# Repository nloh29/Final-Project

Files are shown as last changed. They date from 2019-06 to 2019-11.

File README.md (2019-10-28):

# Final-Project

## Overview:
  Currently, the most common mode of travel around campus is by walking long distances in a short amount of time. This can be a very time consuming and energy consuming process that would greatly benefit from a more efficient mode of transportation. The goal of this project is to create an electric skateboard that allows students to move around campus in a more timely manner that is cheaper, lasts longer, goes faster, and is safer than the current equivalent. This will require firmware to control the board wirelessly using two microcontrollers, the use of motors and motor driver circuits to physically drive the board, charging via USB-C for easier charging access without the need for a specifically dedicated charging solution, and power distribution/regulation for all of the components involved using a safer battery type.

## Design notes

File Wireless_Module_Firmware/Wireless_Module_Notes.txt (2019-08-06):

Wireless Module Notes:

Here is a cypress document that shows what to include into the .gitignore file.
 and what to include to properly push to the repo.

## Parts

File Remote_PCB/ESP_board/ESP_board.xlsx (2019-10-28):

# | Qty: | Designator | Part #: | Manu. | Description | Distributor | Link
1 | 2 | R1,R2 | ESR03EZPJ472 | Rohm Semi. | 4.7 kOhms ±5% 0.25W, 1/4W Chip Resistor 0603 | Digikey | https://www.digikey.com/product-detail/en/rohm-semiconductor/ESR03EZPJ472/RHM4.7KDCT-ND/1762936
2 | 4 | J1,J2,J3,J4 | 68000-210HLF | Amphenol ICC | CONN HEADER VERT 10POS 2.54MM | Digikey | https://www.digikey.com/product-detail/en/68000-210HLF/609-3258-ND/1878529/?itemSeq=307847159
3 | 1 | D1 | Have
4 | 1 | D2 | Have
5 | 1 | J6 | A113320 | Phoenix | TERM BLK 2P SIDE ENT 5.08MM PCB | Digikey | https://www.digikey.com/product-detail/en/282837-2/A113320-ND/2187973

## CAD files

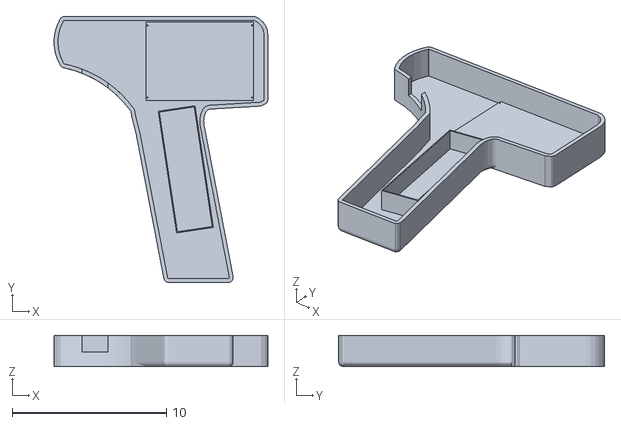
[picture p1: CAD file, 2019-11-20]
Remote_Model/remote_assemblyv2_toPrint.stl
13.9 x 17.2 x 2.03

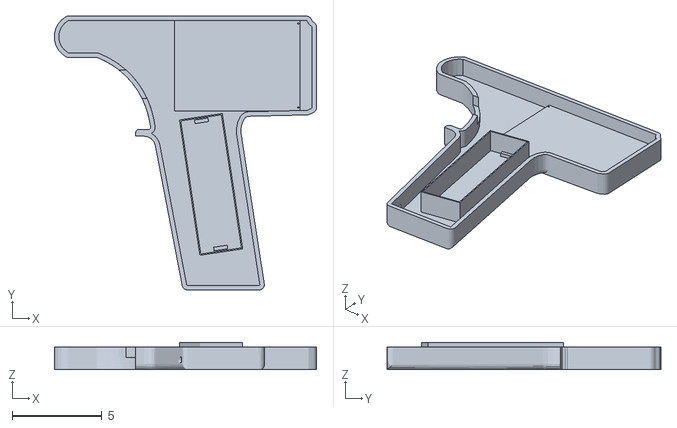
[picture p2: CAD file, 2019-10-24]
Remote_Model/remote_assemblyv2.stl
14.6 x 15.3 x 1.52

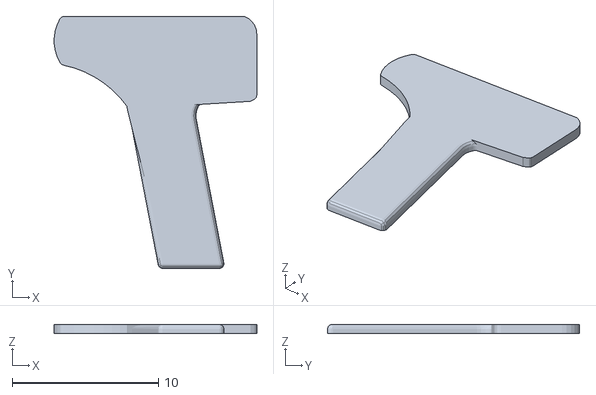
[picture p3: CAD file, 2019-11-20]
Remote_Model/mirror_remote_toPrint.stl
13.9 x 17.2 x 0.635

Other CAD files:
Remote_Model/batteryHousing.ipt
Remote_Model/espHolder.ipt
Remote_Model/remote_assemblyv2.iam
Remote_Model/remote_housing.ipt
Remote_Model/remote_housing_top.ipt
Remote_Model/remote_housing_v2.ipt
Remote_Model/remote_mirrorv2.iam

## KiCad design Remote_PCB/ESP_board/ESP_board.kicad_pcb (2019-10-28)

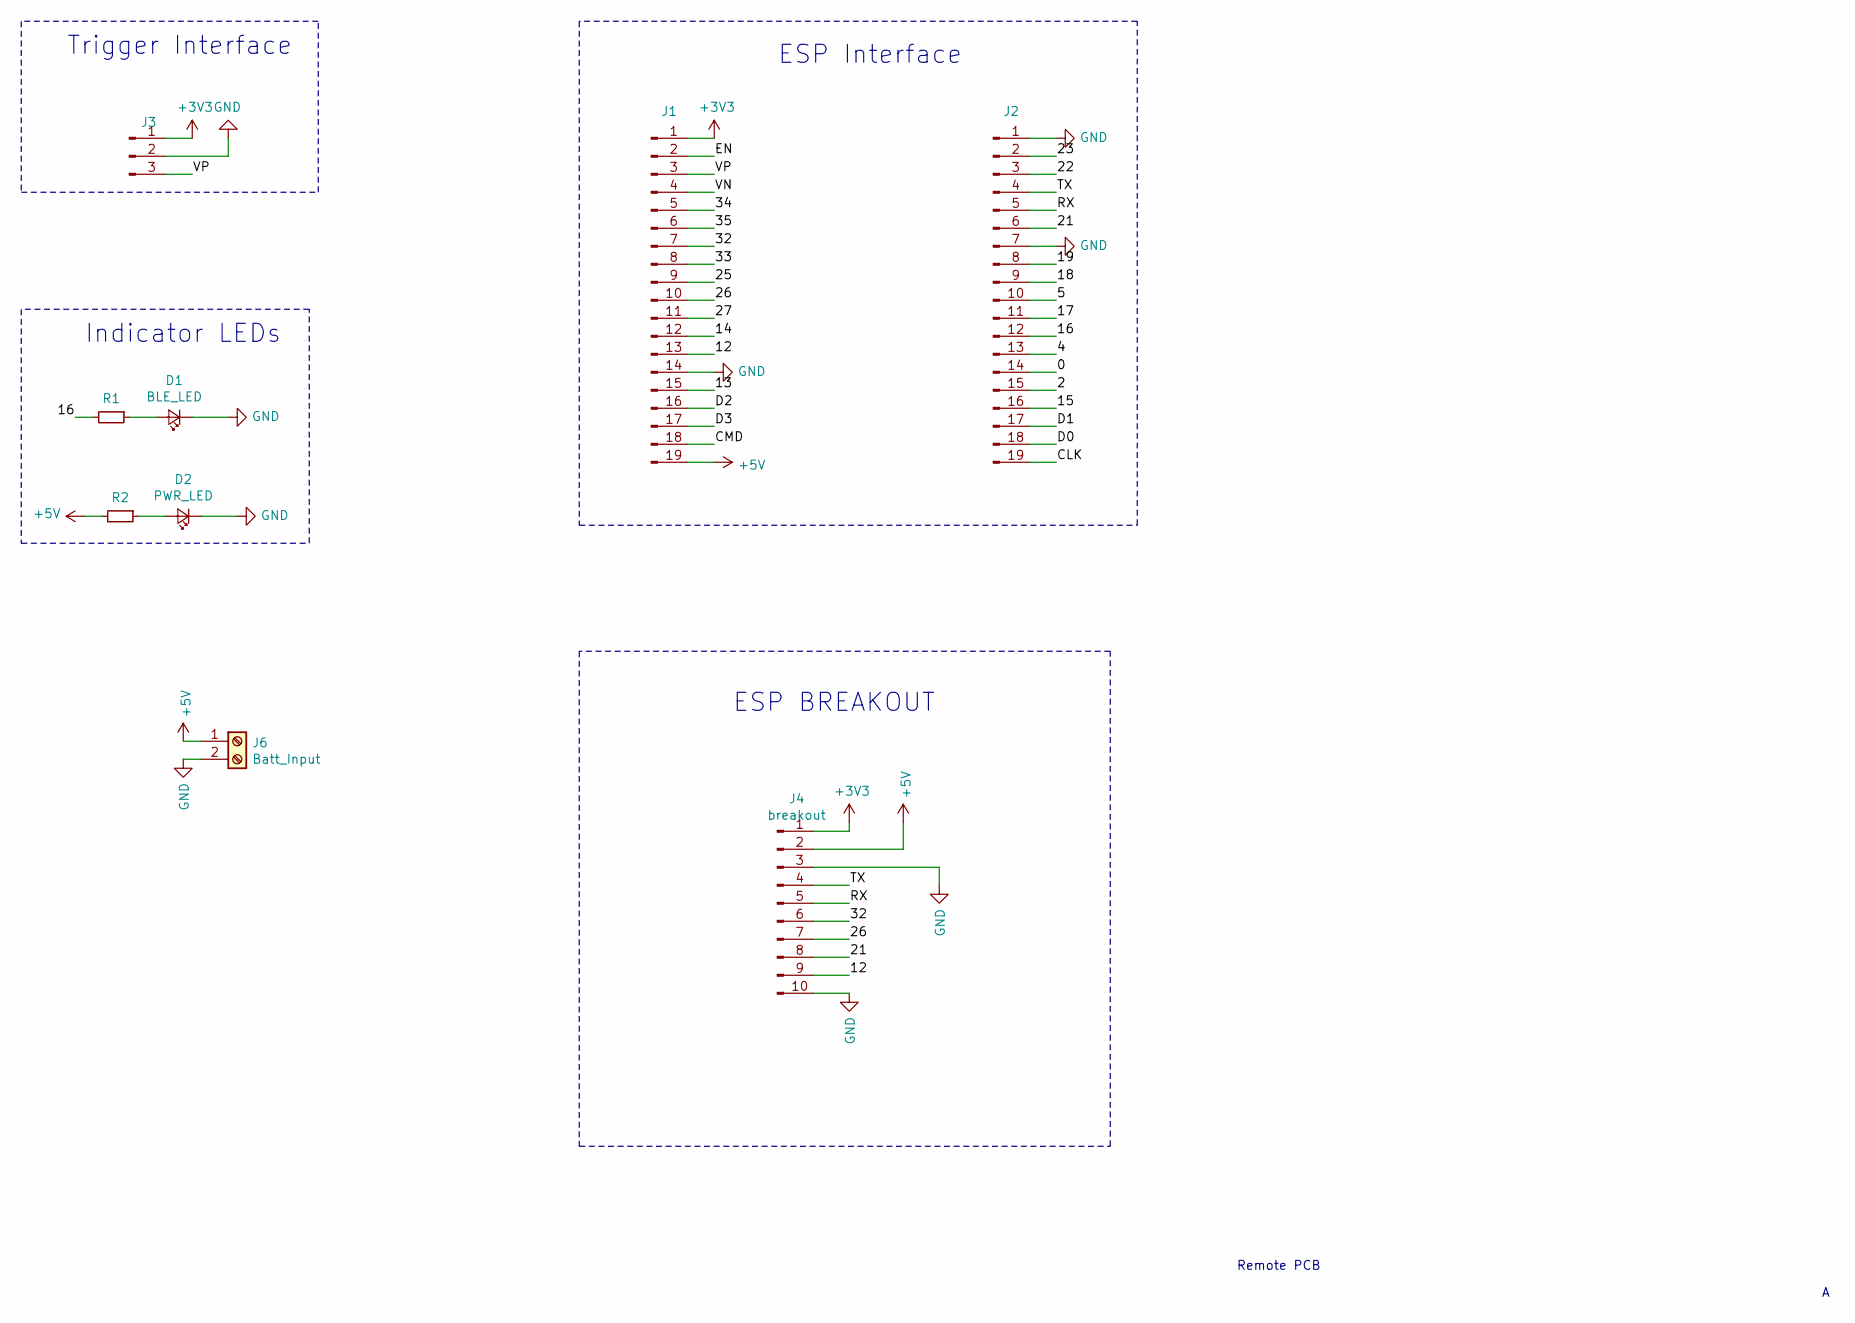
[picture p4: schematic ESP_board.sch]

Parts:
D1: BLE_LED; LED_D2.0mm_W4.0mm_H2.8mm_FlatTop
D2: PWR_LED; LED_D2.0mm_W4.0mm_H2.8mm_FlatTop
J1: leftside; Pin_Header_Straight_1x19_Pitch2.54mm
J2: rightside; Pin_Header_Straight_1x19_Pitch2.54mm
J3: Conn_01x03_Male; Pin_Header_Straight_1x03_Pitch2.54mm
J4: breakout; Pin_Header_Straight_1x10_Pitch2.54mm
J6: Batt_Input; TerminalBlock_bornier-2_P5.08mm
R1, R2: R_Small; R_0603_HandSoldering

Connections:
+3V3: J1.1, J3.1, J4.1
+5V: J1.19, J4.2, J6.1, R2.2
/0: J2.14
/2: J2.15
/4: J2.13
/5: J2.10
/12: J1.13, J4.9
/13: J1.15
/14: J1.12
/15: J2.16
/16: J2.12, R1.2
/17: J2.11
/18: J2.9
/19: J2.8
/21: J2.6, J4.8
/22: J2.3
/23: J2.2
/25: J1.9
/26: J1.10, J4.7
/27: J1.11
/32: J1.7, J4.6
/33: J1.8
/34: J1.5
/35: J1.6
/CLK: J2.19
/CMD: J1.18
/D0: J2.18
/D1: J2.17
/D2: J1.16
/D3: J1.17
/EN: J1.2
/RX: J2.5, J4.5
/TX: J2.4, J4.4
/VN: J1.4
/VP: J1.3, J3.3
GND: D1.1 (K), D2.1 (K), J1.14, J2.1, J2.7, J3.2, J4.3, J4.10, J6.2
unnamed: D1.2 (A), R1.1
unnamed: D2.2 (A), R2.1

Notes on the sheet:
Remote PCB
ESP Interface
Trigger Interface
Indicator LEDs
ESP BREAKOUT

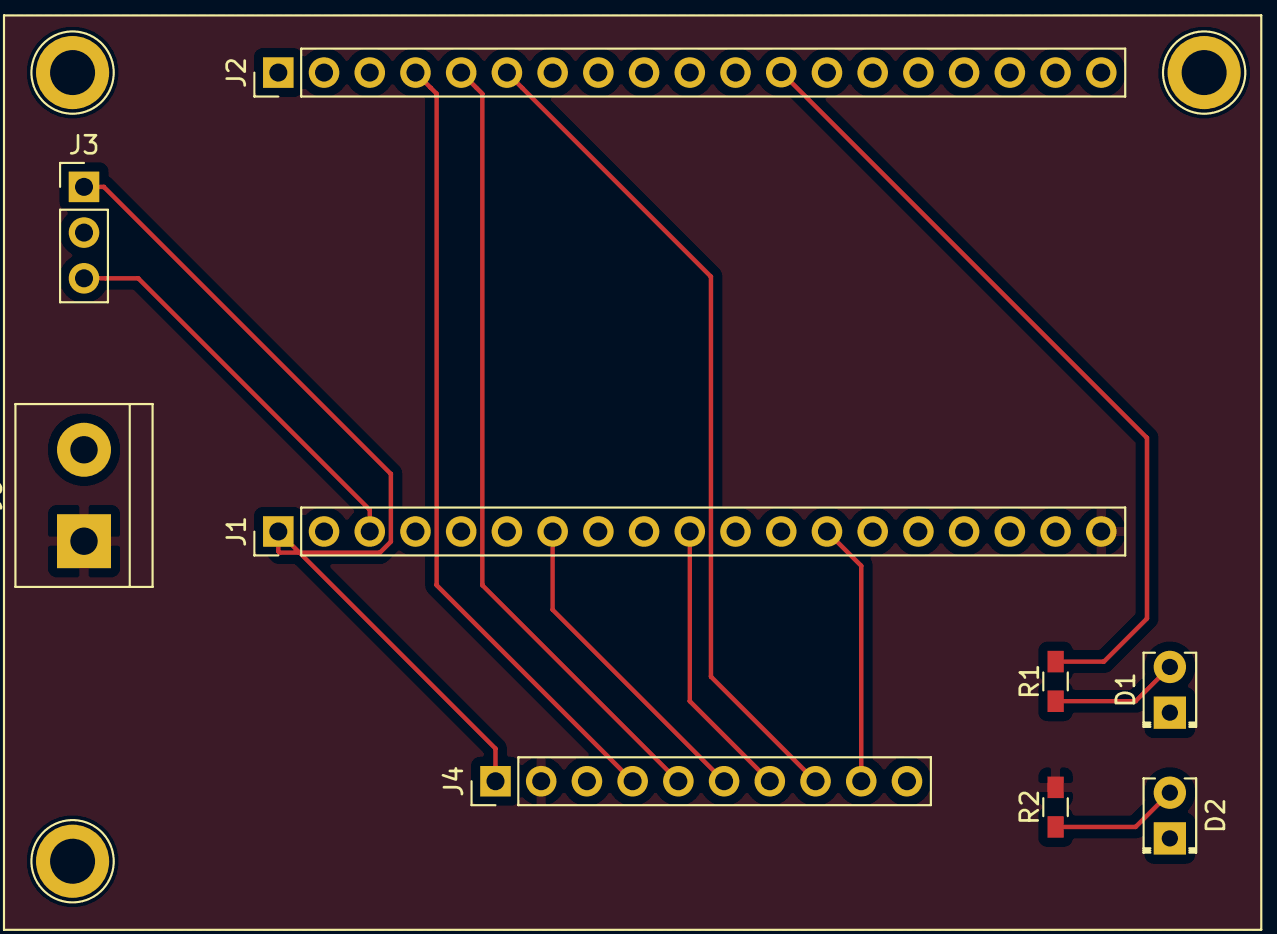
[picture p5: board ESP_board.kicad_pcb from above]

Board: 2 copper layers, 9 parts (0 on the bottom side), 13 nets.

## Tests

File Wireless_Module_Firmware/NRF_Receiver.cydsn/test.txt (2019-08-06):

This folder is for the wireless module firmware

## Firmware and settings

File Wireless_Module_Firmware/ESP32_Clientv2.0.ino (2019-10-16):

#include <cstdlib>
#include <string>
#include <sstream>
#include "BLEDevice.h"
#include "Servo.h"

// The remote service we wish to connect to.
static BLEUUID serviceUUID("4fafc201-1fb5-459e-8fcc-c5c9c331914b");
// The characteristic of the remote service we are interested in.
static BLEUUID    charUUID("beb5483e-36e1-4688-b7f5-ea07361b26a8");

static boolean doConnect = false;
static boolean connected = false;
static int discTimer = 0;
static BLERemoteCharacteristic* pRemoteCharacteristic;
static BLEAddress *pServerAddress;
static BLEClient*  pClient;

Servo esc;
std::string prev_val;
int num_retr = 0;
const int pwmPin = 16;
int pwmVal;
int pwmDuty;
char buff[5];

static void notifyCallback(
  BLERemoteCharacteristic* pBLERemoteCharacteristic,
  uint8_t* pData,
  size_t length,
  bool isNotify) {
   // if(pRemoteCharacteristic->canRead()) {
      discTimer = 0;
      
      //Serial.println((char*)pData);
      std::string value = (char*)pData;
      
      //std::string value = pRemoteCharacteristic->readValue();
      std::stringstream ss(value);
      ss >> pwmVal;
      
      //the server has disconnected and now displays nothing, reconnect
//      if(value == "\0"){
//        Serial.println("Disconnected...");
//        doConnect = true;
//        connected = false;
//        esc.writeMicroseconds(1000);
//      }
      
      //server is connected and getting values
      Serial.print("Val: ");
      Serial.println(pwmVal);
      esc.writeMicroseconds(pwmVal);
    //}
}


class MyClientCallback : public BLEClientCallbacks {
  void onConnect(BLEClient* pclient) {
    connected = true;
    doConnect = false;
  }

  void onDisconnect(BLEClient* pclient) {
    Serial.println("Disconnected...");
    doConnect = true;
    connected = false;
    esc.writeMicroseconds(1000);
  }
};


bool connectToServer(BLEAddress pAddress)
{
	Serial.print("Forming a connection to ");
	Serial.println(pAddress.toString().c_str());

	pClient = BLEDevice::createClient();
	Serial.println(" - Created client");

  pClient->setClientCallbacks(new MyClientCallback());
  
	// Connect to the remove BLE Server.
	pClient->connect(pAddress);
	Serial.println(" - Connected to server");

	// Obtain a reference to the service we are after in the remote BLE server.
	BLERemoteService* pRemoteService = pClient->getService(serviceUUID);
	if (pRemoteService == nullptr) {
		Serial.print("Failed to find our service UUID: ");
		Serial.println(serviceUUID.toString().c_str());
		return false;
	}
	Serial.println(" - Found our service");

	// Obtain a reference to the characteristic in the service of the remote BLE server.
	pRemoteCharacteristic = pRemoteService->getCharacteristic(charUUID);
	if (pRemoteCharacteristic == nullptr) {
		Serial.print("Failed to find our characteristic UUID: ");
		Serial.println(charUUID.toString().c_str());
    pClient->disconnect();
		return false;
	}
	Serial.println(" - Found our characteristic");
    // Read the value of the characteristic.
  if(pRemoteCharacteristic->canRead()) {
    std::string value = pRemoteCharacteristic->readValue();
    Serial.print("The characteristic value was: ");
    Serial.println(value.c_str());
  }

  if(pRemoteCharacteristic->canNotify()){
    pRemoteCharacteristic->registerForNotify(notifyCallback);
  }

}

/**
 * Scan for BLE servers and find the first one that advertises the service we are looking for.
 */
class MyAdvertisedDeviceCallbacks : public BLEAdvertisedDeviceCallbacks {
	/**
	  * Called for each advertising BLE server.
	  */
	void onResult(BLEAdvertisedDevice advertisedDevice) {
		Serial.print("BLE Advertised Device found: ");
		Serial.println(advertisedDevice.toString().c_str());

		// We have found a device, let us now see if it contains the service we are looking for.
		if (advertisedDevice.haveServiceUUID() && advertisedDevice.getServiceUUID().equals(serviceUUID)) {

			// 
			Serial.print("Found our device!  address: ");
			advertisedDevice.getScan()->stop();

			pServerAddress = new BLEAddress(advertisedDevice.getAddress());
			doConnect = true;

		} // Found our server
	} // onResult
}; // MyAdvertisedDeviceCallbacks


void setup() {
	Serial.begin(115200);
  esc.attach(pwmPin);
  esc.writeMicroseconds(1000); //default 'middle' value for motor
  
	Serial.println("Starting Arduino BLE Client application...");
	BLEDevice::init("");

	// Retrieve a Scanner and set the callback we want to use to be informed when we
	// have detected a new device.  Specify that we want active scanning and start the
	// scan to run for 120 seconds.
	BLEScan* pBLEScan = BLEDevice::getScan();
	pBLEScan->setAdvertisedDeviceCallbacks(new MyAdvertisedDeviceCallbacks());
	pBLEScan->setActiveScan(true);
	pBLEScan->start(120);

} // End of setup.


// This is the Arduino main loop function.
void loop() {
	// If the flag "doConnect" is true then we have scanned for and found the desired
	// BLE Server with which we wish to connect.  Now we connect to it.  Once we are 
	// connected we set the connected flag to be true.
	if (doConnect == true) {
		if (connectToServer(*pServerAddress)) {
			Serial.println("We are now connected to the BLE Server.");
			connected = true;
		}
		else {
			Serial.println("We have failed to connect to the server; there is nothing more we will do.");
		}
		doConnect = false;
	}

  else if(discTimer == 20){
    pClient->disconnect();
//    Serial.println("Disconnected...");
//    doConnect = true;
//    connected = false;
//    esc.writeMicroseconds(1000);
    discTimer = 0;
  }

  else{
    discTimer++;
  }
  
//  if (connected == true){
//    //the characteristic is reading (doesn't mean it's connected)
//    if(pRemoteCharacteristic->canRead()) {
//      std::string value = pRemoteCharacteristic->readValue();
//      std::stringstream ss(value);
//      ss >> pwmVal;
//      
//      //the server has disconnected and now displays nothing, reconnect
//      if(value == "\0"){
//        Serial.println("Disconnected...");
//        doConnect = true;
//        connected = false;
//        esc.writeMicroseconds(1000);
//      }
//      
//      //server is connected and getting values
//      else{
//        Serial.print("Val: ");
//        Serial.println(pwmVal);
//        esc.writeMicroseconds(pwmVal);
//        num_retr = 0;
//      }
//    }
//  }
	delay(5); // do a delay to keep things ticking over
}

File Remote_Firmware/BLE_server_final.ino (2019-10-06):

/*
    Based on Neil Kolban example for IDF: https://github.com/nkolban/esp32-snippets/blob/master/cpp_utils/tests/BLE%20Tests/SampleServer.cpp
    Ported to Arduino ESP32 by Evandro Copercini
    updates by chegewara
*/

#include <BLEDevice.h>
#include <BLEUtils.h>
#include <BLEServer.h>
#include<driver/adc.h>
// See the following for generating UUIDs:
// https://www.uuidgenerator.net/

#define SERVICE_UUID        "4fafc201-1fb5-459e-8fcc-c5c9c331914b"
#define CHARACTERISTIC_UUID "beb5483e-36e1-4688-b7f5-ea07361b26a8"
BLECharacteristic *pCharacteristic;

void setup() {
  Serial.begin(115200);
  Serial.println("Starting BLE work!");
  adc1_config_width(ADC_WIDTH_BIT_12);
  adc1_config_channel_atten(ADC1_CHANNEL_0,ADC_ATTEN_DB_11);
  
  BLEDevice::init("server");
  BLEServer *pServer = BLEDevice::createServer();
  BLEService *pService = pServer->createService(SERVICE_UUID);
  pCharacteristic = pService->createCharacteristic(
                                         CHARACTERISTIC_UUID,
                                         BLECharacteristic::PROPERTY_READ |
                                         BLECharacteristic::PROPERTY_WRITE
                                       );

  pCharacteristic->setValue("Hello World says Neil");
  pService->start();
  // BLEAdvertising *pAdvertising = pServer->getAdvertising();  // this still is working for backward compatibility
  BLEAdvertising *pAdvertising = BLEDevice::getAdvertising();
  pAdvertising->addServiceUUID(SERVICE_UUID);
  pAdvertising->setScanResponse(true);
  pAdvertising->setMinPreferred(0x06);  // functions that help with iPhone connections issue
  pAdvertising->setMinPreferred(0x12);
  BLEDevice::startAdvertising();
  Serial.println("Characteristic defined! Now you can read it in your phone!");
}
int count = 1000;
int upcount = 0;
int pin = 0;
int sensor = 0;
void loop() {
//  Serial.print("Sending: ");
 
//  Serial.println(count);
  char buffer[80];
  
    pin = adc1_get_raw(ADC1_CHANNEL_0);
    pin+=1000;
    Serial.println(pin);   
    dtostrf(pin,1,2,buffer);
    pCharacteristic->setValue(buffer);
    delay(10);
    
/*  for(count = 1000; count < 2000;count+=10)
  {
    dtostrf(count,1,2,buffer);
    pCharacteristic->setValue(buffer);
    delay(10);
  }
 for(count = 2000; count > 1000;count-=10)
 {
   
    dtostrf(count,1,2,buffer);
    pCharacteristic->setValue(buffer);
    delay(10);
 }*/

  
  
}

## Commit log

2019-06-28 beginning portion of schematic
    [Remote_PCB.kicad_pcb, Remote_PCB.sch]
2019-09-10 updated schematic
    [Remote_PCB.kicad_pcb, Remote_PCB.sch]
2019-10-06 Add files via upload
    Remote Firmware that reads adc values and transmits
2019-10-06 Added Remote Top and Bottom Piece
    [remote_housing.ipt, remote_housing_top.ipt]
2019-10-06 Added ESP32_Server via upload
    adds averaging for the input ADC values
2019-10-06 Added ESP32_Client added via upload
2019-10-16 Added ESP32_Clientv2.0
    fixed long disconnect timeout using notify and a looping timeout variable. Disconnects after ~100ms of no notifications
    [ESP32_Clientv2.0.ino]
2019-10-23 updated remote
    made remote bigger and added battery housing model to fit in the remote.
    [batteryHousing.ipt, remote_housing_v2.ipt]
2019-10-24 Added remote assembly and STL
    Added remote assembly with battery holder, USB-C cut out, ESP32 Board mounts.
    Also added the STL file so that we can print it.
    [espHolder.ipt, remote_assemblyv2.iam, remote_assemblyv2.stl]
2019-10-26 Added new schematic
    Breakout board for the remote. Board is in intermediate stage of the layout process.
    [ESP_board.kicad_pcb, ESP_board.sch]
2019-10-28 Finished Layout
    [ESP_board-B_Cu.gbr, ESP_board-B_Mask.gbr, ESP_board-B_Paste.gbr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]
2019-10-28 BOM
    Added Final BOM for the remote board.
    [ESP_board.xlsx]
2019-11-20 Added remote model
    Added improved model design that is larger and has a bigger opening for the trigger. Also extended the remote handle so that the battery circuit will fit.
    [mirror_remote_toPrint.stl, remote_assemblyv2_toPrint.stl, remote_mirrorv2.iam]
